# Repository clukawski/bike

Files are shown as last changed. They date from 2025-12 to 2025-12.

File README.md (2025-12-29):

# bike

A ***\~\~work in progress\~\~*** hardtail / rigid bike frame design, produced in OpenSCAD, and  customized for specific measurements.

## Design Features

- EC34/EC34 Headset Compatibility [(Example)](https://www.whiteind.com/product/ec34-ec34/)
- BSA 73mm Threaded Bottom Bracket Shell [(Example: BB2012)](https://www.paragonmachineworks.com/bottom-bracket-shells/steel/steel-threaded-bb-shell-1-562-od.html)
- Planned: [GDH](https://velo-orange.com/blogs/theveloorangeblog/introducing-the-gdh-the-galactic-derailleur-hanger) derailleur hanger

## Sample Render

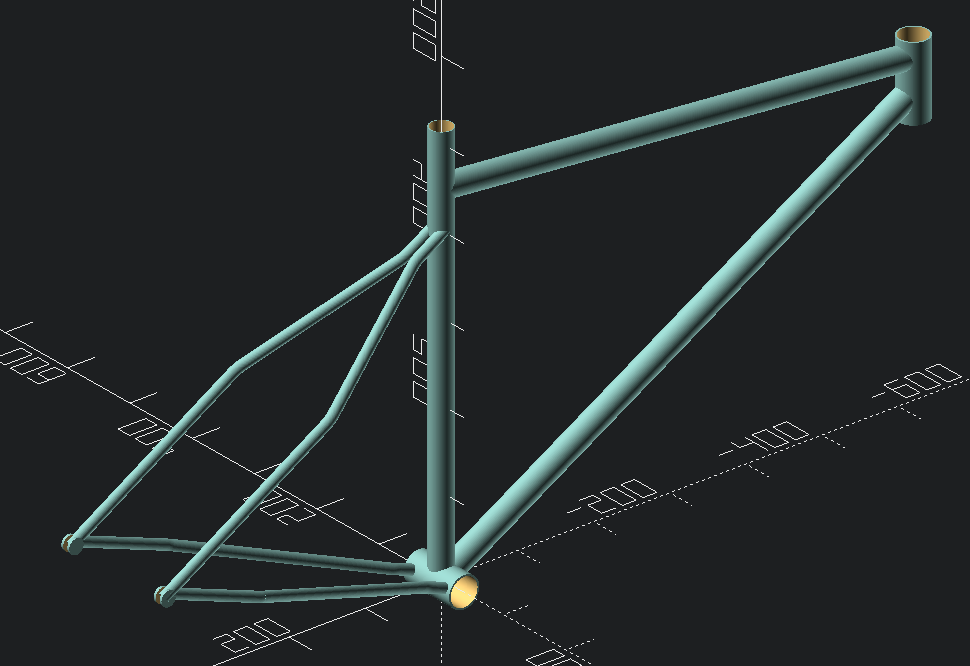
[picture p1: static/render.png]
Hardtail / Rigid Bike Frame Render


## Progress

### Completed

- [x] Front and rear triangle
- [x] Components are modularized, and measurements / transforms are defined per part
- [x] All components rendered with cuts so they can be rendered individually and 3D printed to use as live mocks

### WIP
- [x] Seat stay / chain stays
  - [x] Ensure right (drive side) seatstay / chainstay is offset enough for freehub cassette
  - [x] Ensure width between stays matches freehub axle width (probably needs tweaking)
  - [x] Tweak length / positioning of stays for 27.5" wheels
  - [ ] Make chain / seatstays use realistic bends
  - [ ] Generate chain / seat stay shapes depending on specified part sizes and bend angles
  - [ ] Put stay generation functions / modules back into `bframe_parts.scad`
- [ ] Dropouts ?? (probably the "mount" piece just needs some modifications / cuts for axle)
- [ ] Derailleur hanger mount, planning on [GDH](https://velo-orange.com/blogs/theveloorangeblog/introducing-the-gdh-the-galactic-derailleur-hanger)
- [ ] Cable routing

### Planned Long-term Goals

- [ ] Have both rigid and suspension corrected versions

### Stretch Goals

- [ ] Create parent bike frame module that takes arbitrary geometry and material inputs, and adjusts rotations, offsets/translations, and part lengths to generate custom frames

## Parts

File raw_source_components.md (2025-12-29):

# 4130 tubing sources and dimensions

## mcmaster-carr

### radius

| part | OR mm. | Wall Depth mm. | IR cm. | Wt. / Ft. | ID | Price / Unit.  |
|---|---|---|---|---|---|---|
| seat/top tube |  14.2875 | 1.2446 |  13.0429 | ??? |  89955K929 | (ft) $14.81 |
| bottom tube | 14.28751 | 0.889 |  13.3985 | ??? |  89955K919 | (ft) $14.19 |
| (bsa) bb tube | 19.84375 | 2.2479 | 17 | ??? |  See below |  (unit) $11.95 |
| (ec34/ec34 reamed) head tube | 19.05 | 2.413 |  16.9418 | ??? |  89955K689 | (ft) $21.15 |
| chainstay / rear triangle | 6.35 | 1.4732 | 4.8768 | ??? |  89955K138 | (ft) $12.21 |

#### bottom bracket shell
https://www.paragonmachineworks.com/bottom-bracket-shells/steel/steel-threaded-bb-shell-1-562-od.html

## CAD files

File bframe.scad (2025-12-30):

// Define bike frame properties, and render parts with intersection cuts
//
// This file contains 2.5-ish sections:
// - Material / Part Definitions
// - Rendering Front Triangle Parts / Cuts
// - Rendering Rear Triangle Parts / Cuts

// Include part modules for rendering
use <bframe_parts.scad>;

function bend_offset_a(angle_a, len_c)
    = (((len_c*sin(90-angle_a))/sin(90))*sin(angle_a))/sin(90-angle_a);
function bend_offset_b(angle_a, len_c)
    = ((len_c*sin(90-angle_a))/sin(90));

/*
  Define Material / Part Constraints:
  - Material Source (Link / Product Code)
  - Part Outer Radius (or_*)
  - Part Inner Radius (ir_*)
  - Part Length (len_*)
  - Rotations (rot_*)
  - Translations / Offsets (trans_* / offset_*)
  - Curve Offsets for Stays / Curved Parts (curve_offset_*)
*/

// Special values for curved parts
$fa=1;
$fs=0.5;

// Seat Tube
//
// Raw Material Dimensions
//
// McMaster-Carr 89955K929
len_seat=520;
or_seat=14.2875;
ir_seat=13.0429;

// Bottom Bracket Tube
//
// Raw Material Dimensions
//
// Paragon Machineworks Steel Threaded BB Shell
// - https://www.paragonmachineworks.com/bottom-bracket-shells/steel/steel-threaded-bb-shell-1-562-od.html
len_bb=73;
rot_bb=[0,90,0];
offset_bb_x=-len_bb/2;
trans_bb=[offset_bb_x,0,0];
or_bb=19.8374;
ir_bb=17.5895;

// Top Tube with Cuts
//
// Raw Material Dimensions
//
// McMaster-Carr 89955K929
len_top=620;
rot_top=[95,0,0];
trans_top=[0,0,450];
or_top=14.2875;
ir_top=13.0429;

// Bottom Tube
//
// Raw Material Dimensions
//
// McMaster-Carr 89955K919
len_bottom=710;
or_bottom=14.2875;
ir_bottom=13.3985;
rot_bottom=[60,0,0];

// Head Tube
//
// Raw Material Dimensions
//
// McMaster-Carr 89955K689
len_head=95;
or_head=19.05;
ir_head=16.9418;
trans_head=[0,-len_top,325];

// Common Stay Values
//
// Raw Material Dimensions
//
// McMaster-Carr 89955K138
or_stay=6.35;
ir_stay=4.8768;
offset_stay=170;
offset_dropout_mount_x_r=-74;
offset_dropout_mount_x_l=74;
offset_seatstay_dropout=45;

// Chainstays
bend_radius_chainstay=50.8;
bend_angle_chainstay=10;
len_chainstay=440;
len_chainstay_divisor=21;
// Angle Relative to Bottom Bracket Tube
angle_chainstay=20;

// Seatstays
bend_radius_seatstay=50.8;
bend_angle_seatstay=45;
len_seatstay=485;
len_seatstay_divisor=14;
len_seatstay_first_segment_multiplier=0.9;
// Angle Relative to Bottom Bracket Tube
angle_seatstay=31;
bend_positions_seatstay=[0.90,0.28];
or_mult_seatstay_seat_tube=2.5;

// Seatstay Right
//
// Raw Material Dimensions
//
// McMaster-Carr 89955K138
len_seatstay_r=500;
rot_seatstay_r=[60,-8,0];
trans_seatstay_r=[offset_dropout_mount_x_r,len_seatstay_r-offset_seatstay_dropout,offset_stay];
curve_offset_seatstay_r=-95;

// Seatstay Left
//
// Raw Material Dimensions
//
// McMaster-Carr 89955K138
len_seatstay_l=515;
rot_seatstay_l=[60,8,0];
trans_seatstay_l=[offset_dropout_mount_x_l,len_seatstay_l-offset_seatstay_dropout,offset_stay];
curve_offset_seatstay_l=95;

// Temporary Dropout "Mounts"
//
// 142x12 boost spacing HG freehub
//
// Example:
// - Shimano Deore XT FH-M8110-B 148mm Rear hub
//   - https://kstoerz.com/freespoke/hub/534
len_rear_hub=148;
// Generic 3/4" 4130 Round  Bar
or_dropout_mount=9.525;
len_dropout_mount=or_stay*2;
offset_dropout_mount_z=150;
trans_dropout_mount_r=[len_rear_hub/2,bend_offset_b(angle_chainstay, len_chainstay)+or_dropout_mount*1.1,bend_offset_a(angle_chainstay, len_chainstay)];
trans_dropout_mount_cut_r=[len_rear_hub/2,bend_offset_b(angle_chainstay, len_chainstay)+or_dropout_mount*1.1,bend_offset_a(angle_chainstay, len_chainstay)];
trans_dropout_mount_l=[-len_rear_hub/2,bend_offset_b(angle_chainstay, len_chainstay)+or_dropout_mount*1.1,bend_offset_a(angle_chainstay, len_chainstay)];
trans_dropout_mount_cut_l=[-len_rear_hub/2,bend_offset_b(angle_chainstay, len_chainstay)+or_dropout_mount*1.1,bend_offset_a(angle_chainstay, len_chainstay)];
rot_dropout_mount=[0,90,0];

/*
  Render Front Triangle:
  - Seat Tube
  - Bottom Bracket Tube
  - Top Tube
  - Bottom Tube
  - Head Tube
*/

// Render Bottom Bracket Tube (No Cuts)
bb_tube(trans_bb, rot_bb, or_bb, ir_bb, len_bb);

// Render Seat Tube with Cuts
difference() {
    seat_tube(or_seat, ir_seat, len_seat);
    bb_tube(trans_bb, rot_bb, or_bb, ir_bb, len_bb, hollow=false);
}

// Render Top Tube with Cuts
difference() {
    top_tube(trans_top, rot_top, or_top, ir_top, len_top);
    seat_tube(or_seat, ir_seat, len_seat, hollow=false);
    head_tube(trans_head, or_head, ir_head, len_head, hollow=false);
}

// Render Bottom Tube with Cuts
difference() {
    bottom_tube(rot_bottom, or_bottom, ir_bottom, len_bottom);
    seat_tube(hollow=false);
    head_tube(trans_head, or_head, ir_head, len_head, hollow=false);
    bb_tube(trans_bb, rot_bb, or_bb, ir_bb, len_bb, hollow=false);
}

// Render Head Tube (No Cuts)
head_tube(trans_head, or_head, ir_head, len_head);

/*
  Render Rear Triangle:
  - Chainstay Right
  - Chainstay Left
  - Seatstay Right
  - Seatstay Left
  - Dropouts
  - Derailleur Hanger
*/

module wall2D(thickness)
  difference()
  {
    offset(thickness)
      children(0);
    children(0);
  }
 
module elbowinator(angle, bendRadius, clipBounds=1000, convexity=4)
  intersection(convexity=convexity)
  {
    rotate_extrude(convexity=convexity)
      translate([bendRadius,0,0])
        children(0);
    linear_extrude(height=clipBounds, slices=2, center=true)   
      wedge2D(angle, clipBounds);
  }

module wedge2D(angle, r, nSides=3) 
  polygon(points=concat([[0,0]], [for(i=[0:nSides]) r*[cos(i/nSides*angle), sin(i/nSides*angle)]]), convexity=4);

module genstay(trans, rot, bend_radius, bend_angle, divisor, length, length_bb, outer_radius, inner_radius, outer_radius_bb, first_segment_multiplier=1, bends=[0.38,0.72], hollow=true) {

    rotate(rot) {
        offset_stay_total_x_r=(length_bb/2)-(divisor/2);
        offset_stay_total_y_r=outer_radius_bb/2;
        len_first_straight=length/divisor;
        length_first_offset=len_first_straight*first_segment_multiplier-len_first_straight;

        // First Segment
        translate([-offset_stay_total_x_r,offset_stay_total_y_r+bend_offset_a(bend_angle, bend_radius)-length_first_offset,0])
            tube_hollow([0,0,0], [-90,0,0], outer_radius, inner_radius, first_segment_multiplier*len_first_straight, hollow);

        // First Elbow
        translate([
          -offset_stay_total_x_r-bend_radius,
          offset_stay_total_y_r+bend_offset_a(bend_angle, bend_radius)+len_first_straight,
          0,
        ])
            rotate([0,0,0])
                elbowinator(angle=bend_angle, bendRadius=bend_radius)
                    wall2D(thickness=outer_radius-inner_radius)
                        circle(r=inner_radius);

        // Second Segment
        trans_second_straight=[
            -offset_stay_total_x_r-bend_radius+bend_offset_b(bend_angle, bend_radius),
            offset_stay_total_y_r+len_first_straight+bend_offset_a(bend_angle, bend_radius)*2,
            0,
        ];
        len_second_straight=len_first_straight*(divisor-(divisor*bends[0]));
        tube_hollow(trans_second_straight, [-90,0,bend_angle], outer_radius, inner_radius, len_second_straight, hollow);

        translate(trans) {
            // Second Elbow
            translate([
                -offset_stay_total_x_r-(bend_radius-bend_offset_b(bend_angle, bend_radius))-bend_offset_a(bend_angle, len_second_straight)+bend_radius,
                (offset_stay_total_y_r+len_first_straight+len_second_straight+bend_offset_a(bend_angle, bend_radius)*2),
                 0,
             ])
                rotate([0,180,bend_angle])
                    elbowinator(angle=bend_angle, bendRadius=bend_radius)
                        wall2D(thickness=outer_radius-inner_radius)
                        circle(r=inner_radius);

            // Third Segment
            trans_third_straight=[
                -offset_stay_total_x_r-(bend_radius-bend_offset_b(bend_angle, bend_radius))-bend_offset_a(bend_angle, len_second_straight),
                offset_stay_total_y_r+len_first_straight+len_second_straight+bend_offset_a(bend_angle, bend_radius)*2,
                0,
            ];
            len_third_straight=len_first_straight*(divisor-(divisor*bends[1]));
            tube_hollow(trans_third_straight, [-90,0,0], outer_radius, inner_radius, len_third_straight, hollow);
        }
    }
}

// Render Chainstay Right
genstay(
    [0,0,0],
	[20,0,0],
	bend_radius_chainstay,
	bend_angle_chainstay,
	len_chainstay_divisor,
	len_chainstay,
	len_bb,
    or_stay,
    ir_stay,
	or_bb);

// Render Chainstay Left
genstay(
    [0,0,0],
	[-20,180,0],
	bend_radius_chainstay,
	bend_angle_chainstay,
	len_chainstay_divisor,
	len_chainstay,
	len_bb,
    or_stay,
    ir_stay,
	or_bb);
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

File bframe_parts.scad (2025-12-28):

// Part module definitions

// Generic hollow tube
module tube_hollow(trans, rot, outer_radius, inner_radius, length, hollow=true) {
	translate(trans)
		rotate(rot)
		if (hollow==true) {
			difference() {
				cylinder(r=outer_radius, h=length);
				cylinder(r=inner_radius, h=length);
			}
		} else {
			cylinder(r=outer_radius, h=length);
		}
}

// Seat Tube
module seat_tube(outer_radius, inner_radius, length, hollow=true) {
	tube_hollow([0,0,0], [0,0,0], outer_radius, inner_radius, length, hollow);
}

// BB Tube
module bb_tube(trans, rot, outer_radius, inner_radius, length, hollow=true) {
	tube_hollow(trans, rot, outer_radius, inner_radius, length, hollow);
}

// Top Tube
module top_tube(trans, rot, outer_radius, inner_radius, length, hollow=true) {
	tube_hollow(trans, rot, outer_radius, inner_radius, length, hollow);
}

// Head Tube
module head_tube(trans, outer_radius, inner_radius, length, hollow=true) {
	tube_hollow(trans, [0,0,0], outer_radius, inner_radius, length, hollow);
}

// Bottom Tube
module bottom_tube(rot, outer_radius, inner_radius, length, hollow=true) {
	tube_hollow([0,0,0], rot, outer_radius, inner_radius, length, hollow);
}

// Generate any kind of chain/seat stay curved pipe
module raw_stay (curve_offset, length, radius) {
    radius_stay = (curve_offset^2 + length^2) / 2 / curve_offset;
    angle_stay = asin(length / (radius_stay - curve_offset));
    rotate([90, 0, 0]) translate([-radius_stay, 0, 0]) rotate_extrude(angle=angle_stay) translate([radius_stay, 0]) circle(radius);
}

// Generate optionally (and by default) hollow chain/seat stay
module stay(trans, rot, curve_offset, outer_radius, inner_radius, length, hollow=true) {
	translate(trans)
		rotate(rot)
		if (hollow==true) {
			difference() {
				raw_stay(curve_offset, length, outer_radius);
				raw_stay(curve_offset, length, inner_radius);
			}
		} else {
			raw_stay(curve_offset, length, outer_radius);
		}
}

// Dropout Mounts
module dropout_mount(trans, rot, radius, length) {
    translate(trans)
        rotate(rot)
		    cylinder(r=radius, h=length, center=true);
}

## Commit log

2025-12-28 Initial commit, with front triangle and chainstays completed
    [bframe_hardtail.scad]
2025-12-28 Clean up code a bit
    [bframe_hardtail.scad]
2025-12-28 Add seatstays and widen rear triangle wheel area
    [bframe_hardtail.scad]
2025-12-28 Fully modularize parts, and do cuts as part of chain/seat stay rendering
    [bframe_hardtail.scad]
2025-12-28 Organize cuts for front triangle at render time instead of in the module
    [bframe_hardtail.scad]
2025-12-28 Add temporary dropout "mount" filler piece and add additional stay cuts
    [bframe_hardtail.scad]
2025-12-28 Add missing comments
    [bframe_hardtail.scad]
2025-12-28 Add cable routing to WIP
2025-12-28 Fix missing cut for bottom tube
    [bframe_hardtail.scad]
2025-12-28 Add seat/chainstay drive side adjustments to top of WIP list
2025-12-28 Reduce repeated operations, and refactor code into parts / assembly files
    [bframe.scad, bframe_hardtail.scad, bframe_parts.scad]
2025-12-28 De-duplicate code and remove global dependencies from modules
    [bframe.scad, bframe_parts.scad]
2025-12-28 Rear triangle adjustments
    [bframe.scad, bframe_parts.scad]
2025-12-28 More fucking triangles
    [bframe.scad]
2025-12-28 Use narrower tubing for rear triangle and geometry for boost FH + tire spacing
    [bframe.scad]
2025-12-29 Move seat/chain stay ajustments from WIP to completed
2025-12-29 Tweaks to front triangle geometry
    [bframe.scad]
2025-12-29 Front geometry tweaks + updated render
    [bframe.scad]
2025-12-29 Update README.md
    Specify 73mm BB shell instead of 68mm.
2025-12-29 Minor tweak to internal diameter of BB tube to prepare for adding threads
    [bframe.scad]
2025-12-29 Updated stay gen to use realistic bends and relative angles / part sizes for inputs
    [bframe.scad]
2025-12-30 Janky but working chain and seat stays with practical bends
    [bframe.scad]
2025-12-30 Make room for larger tires
    [bframe.scad]
